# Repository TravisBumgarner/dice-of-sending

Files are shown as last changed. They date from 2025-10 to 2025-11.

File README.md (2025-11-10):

# Dice of Sending

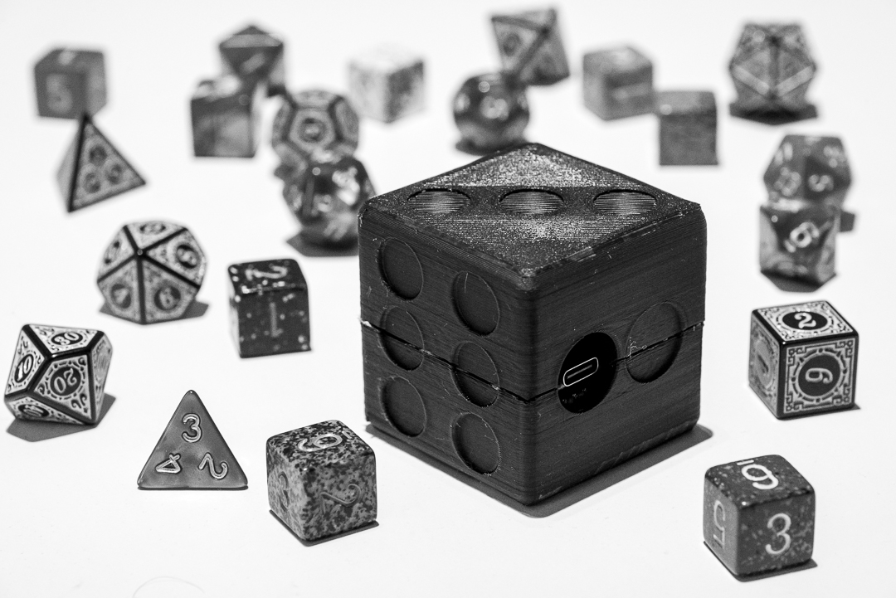
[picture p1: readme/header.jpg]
Finished D6 dice


**Wondrous Item, uncommon**

When a Dungeon Master insists you roll in plain sight, the Dice of Sending offer a clever loophole. These enchanted dice are linked by invisible arcane currents (or Bluetooth, depending on your realm’s tech level), allowing a roll in both the physical and digital planes simultaneously.

Those attuned to the Dice of Sending may appear obedient while still indulging their chaotic good nature—rolling fairly, yet unpredictably.

# Preface

This project is still a work in progress and is mostly there but there are still some rough edges.

[Join the discussion on Discord](https://discord.gg/wJ8eyUJk) (Check the `#dice-of-sending` channel).

# Fairness

With the latest version, I test rolled 210 times

- 1 - 34
- 2 - 31
- 3 - 41
- 4 - 37
- 5 - 36
- 6 - 31

# Quick Start

Full setup below.

1. Solder Seed Studio, battery, and accelerometer together.
1. Calibrate dice with `arduino/calibration/calibration.ino`
1. Add calibration values to `arduino/dice_of_sending/dice_of_sending.ino`.
1. Run website with `cd website && npm bootstrap && npm run dev` (Or visit [Dice of Sending](https://dice.pointlessprojects.com/) if still hosted.)
1. Open website, invite friends to a room, connect to dice, start playing board games.

```
const device = await navigator.bluetooth.requestDevice({
    filters: [{ namePrefix: "old-name-here" }],
    optionalServices: ["deadbeef-1234-5678-1234-56789abcdef0"],
});
```

# Future Functionality

These are things I'll maybe do in the future, or you can too!

**Low power mode**

When the dice aren't being rolled, go to sleep to save power.

# Setup

## Tools

1. Hot glue gun
1. Soldering iron
1. [Arduino IDE](https://www.arduino.cc/en/software/)

## Parts

1. 1× `USB-C cable`
1. 1× `Seeed Studio XIAO nRF52840` (Or any Arduino device with Bluetooth)
1. 1× `BMI160 accelerometer + gyroscope`
1. 1× `3.7V 60mAh 0.22Wh battery`
1. 1x 38cm x 38cm Protoboard
1. `PCB wire`

## Code

- `dice_of_sending/` — Final Code.
- `bluetooth/` — Test bluetooth communication. Upload sketch then open the `bluetooth.html` file in the browser.
- `acceleration/` — Test accelerometer. Upload sketch and open `Tools → Serial Monitor` with the Arduino software.
- `calibration/` — Calibrate dice values. Copy output to `dice_of_sending/`.

## Circuit

**References**

- [Seeed Studio XIAO nRF52840](https://wiki.seeedstudio.com/XIAO_BLE/)
- [BMI160 3 Axis Accelerometer & Gyroscope](https://how2electronics.com/interfacing-bmi160-accelerometer-gyroscope-with-arduino/)

## Soldering

1. Solder the battery to the microcontroller pads before soldering the microcontroller to the protoboard.
1. Solder the following connections between the Seeed Studio XIAO nRF52840 and BMI160 using the references above.

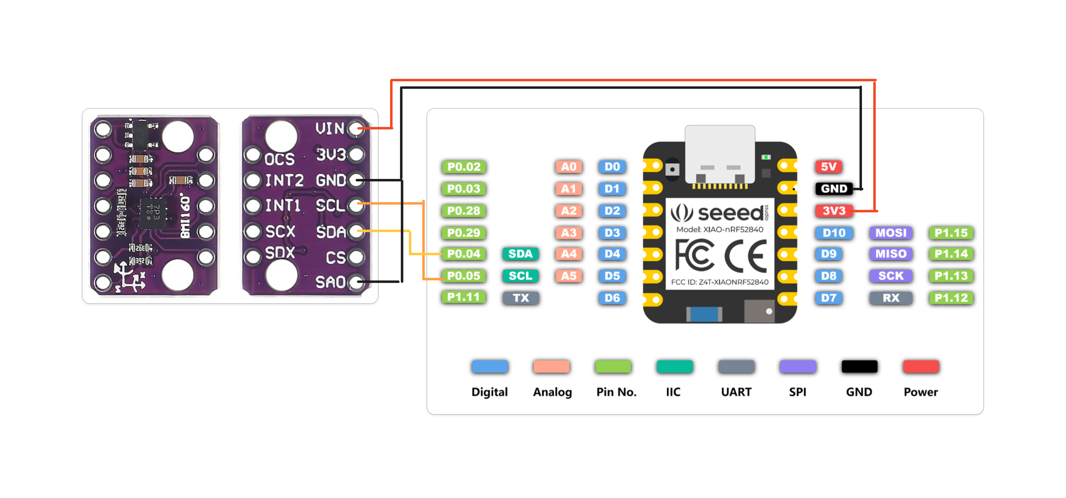
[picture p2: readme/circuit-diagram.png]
Circuit diagram

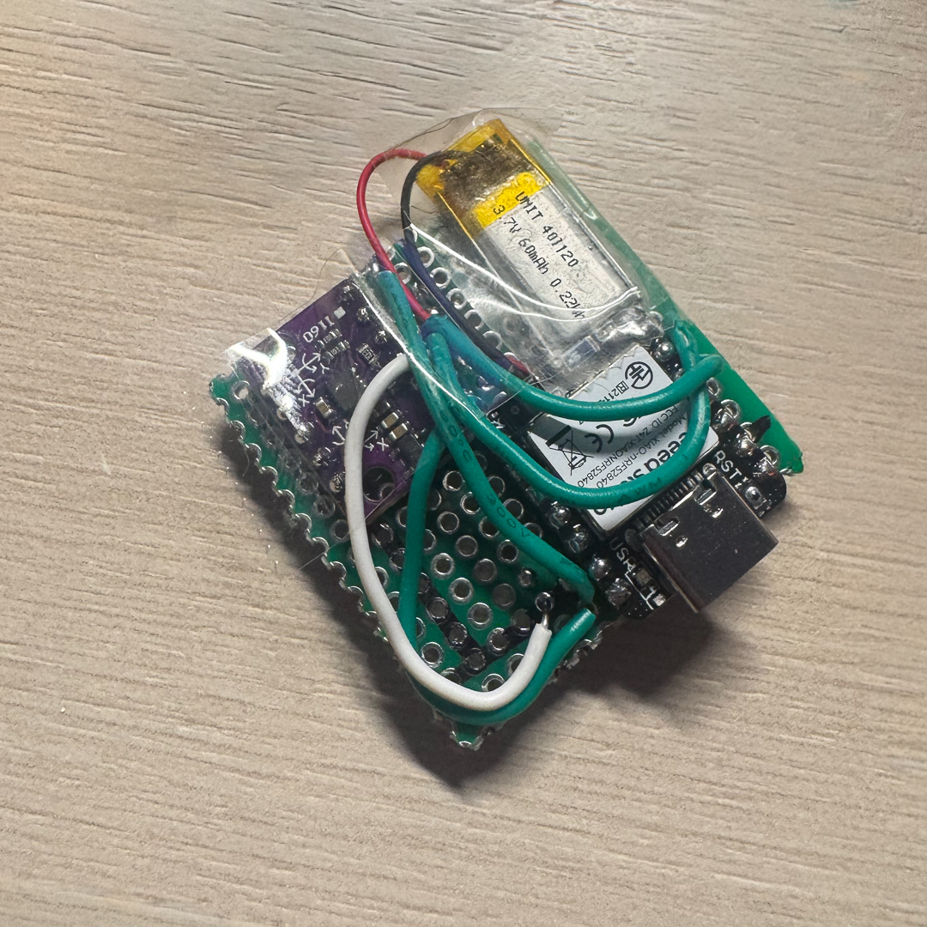
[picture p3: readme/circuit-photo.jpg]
Circuit photo


## 3D Models

- STLs can be found in `cad/`.
- Onshape models can be found [here](https://cad.onshape.com/documents?nodeId=a9d0374e84dc054d840f8403&resourceType=folder). Use the V2 Models.

1. Print models. I opted for 60% infill. 
1. Place some hot glue on each of the four corners. 
1. Place circuit inside.
1. Place some more hot glue along the edges of the circuit. 
1. Hot glue the two halves together.

## Website

The site may or may not still be hosted [here](https://dice.pointlessprojects.com/).

### Run locally

1. `cd website`
1. [Install Node and npm](https://docs.npmjs.com/downloading-and-installing-node-js-and-npm)
1. Install dependencies — `npm bootstrap`
1. Start website — `npm run dev`

### Deploy

1. Get a domain.
1. Point `website/frontend/src/services/socket.ts` towards your domain.
1. Build `npm run build` - This will give you an Express server that runs the socket connection and serves the React app.
1. Deploy somewhere.
1. Enjoy!

# Known Issues

These are either bugs in the code or quirks/shortcomings.

**Arduino Software can't find device**

Sometimes the device needs to be reconnected a few times before it shows up in Arduino.

**Bluetooth Naming**

It appears that it takes some time for the browser to recognize a name change of `BLE.setLocalName("Arduino");` within the Arduino code. If the device stops showing up and you changed the name, try searching for the old name within the HTML code:

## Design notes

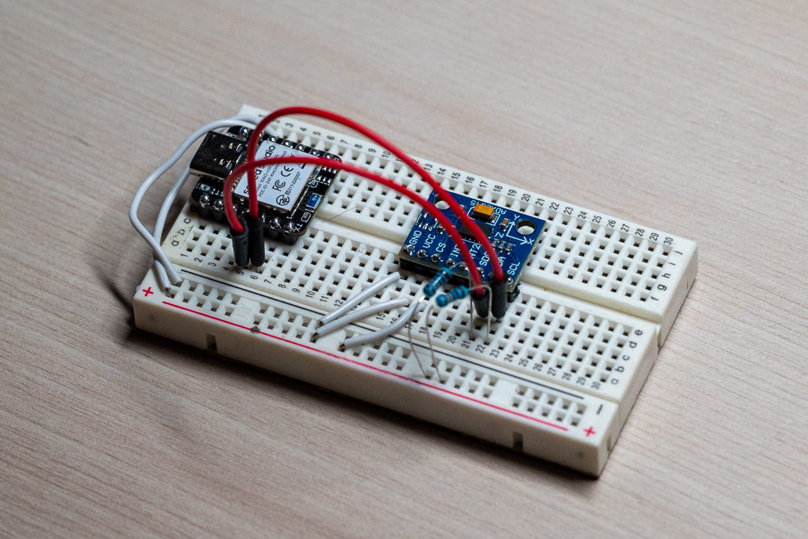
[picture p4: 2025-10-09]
readme/breadboard.jpg

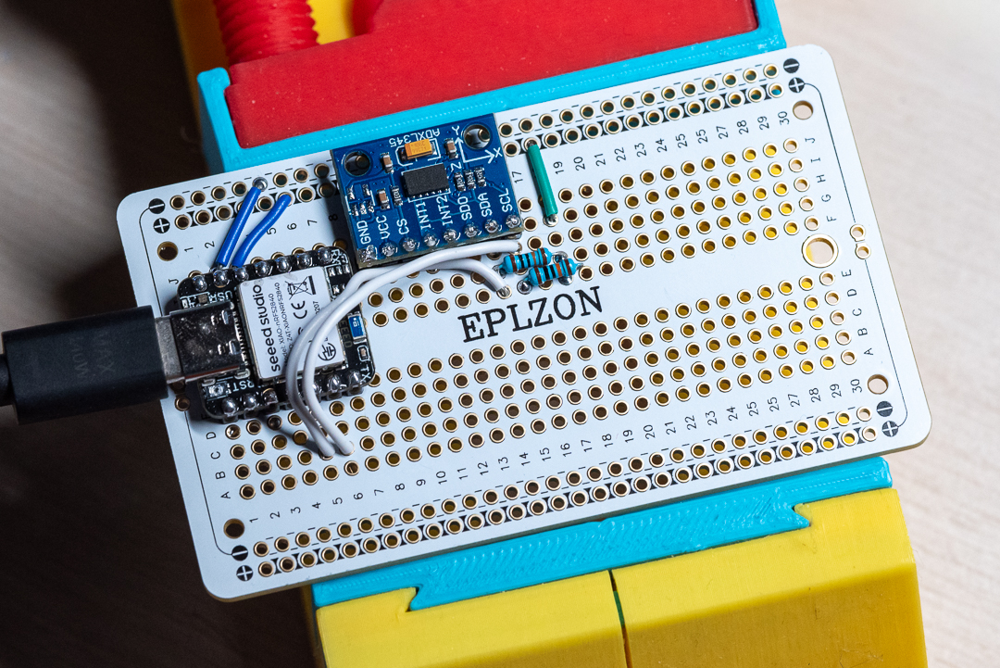
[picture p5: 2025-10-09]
readme/protoboard.jpg

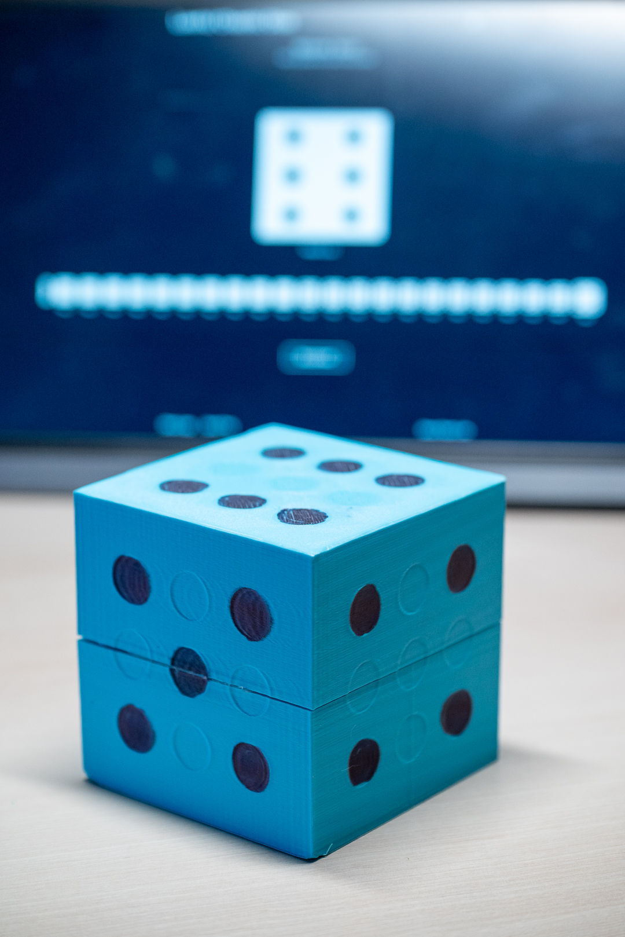
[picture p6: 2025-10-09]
readme/final.jpg

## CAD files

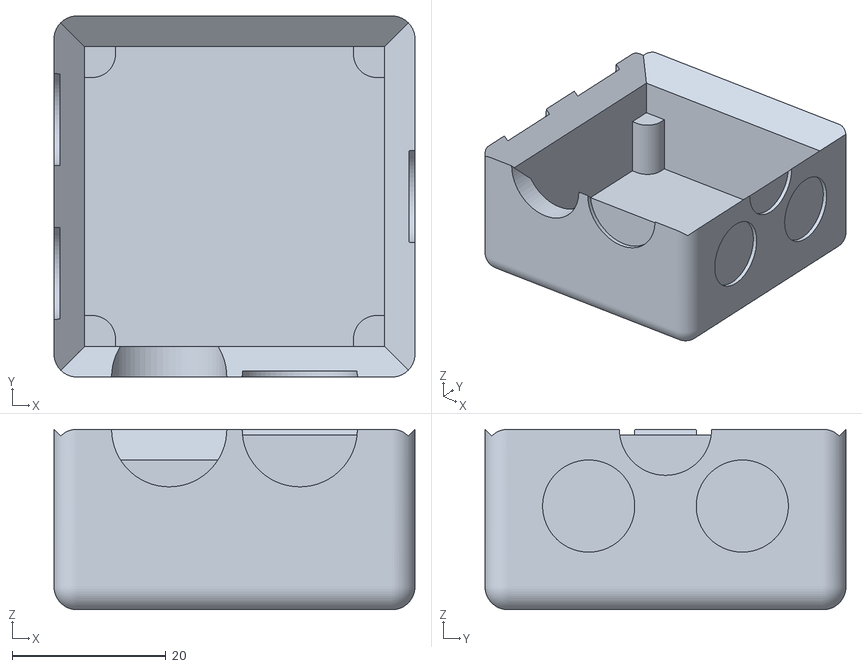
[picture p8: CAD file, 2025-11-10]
cad/Dice V3 - Bottom.stl
47.0 x 47.0 x 23.5

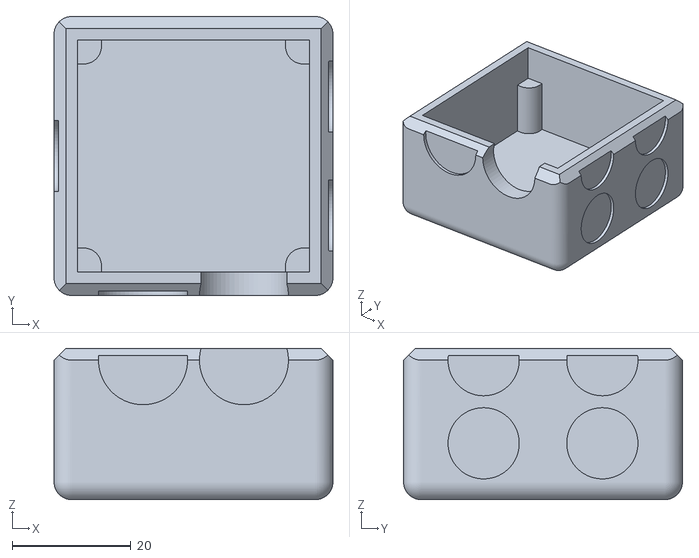
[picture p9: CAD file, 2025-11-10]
cad/Dice V3 - Top.stl
47.0 x 47.0 x 25.5

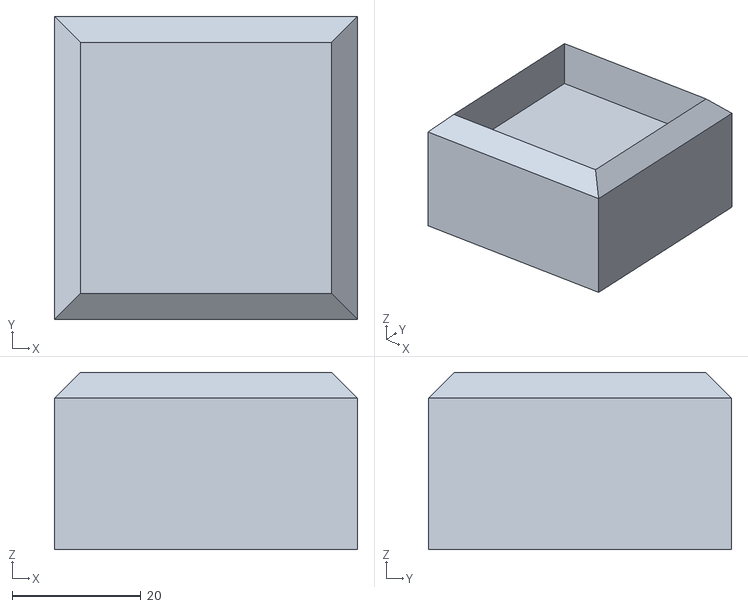
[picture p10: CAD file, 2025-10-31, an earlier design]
archive/cad/Dice V2 - Top.stl
47.0 x 47.0 x 27.5

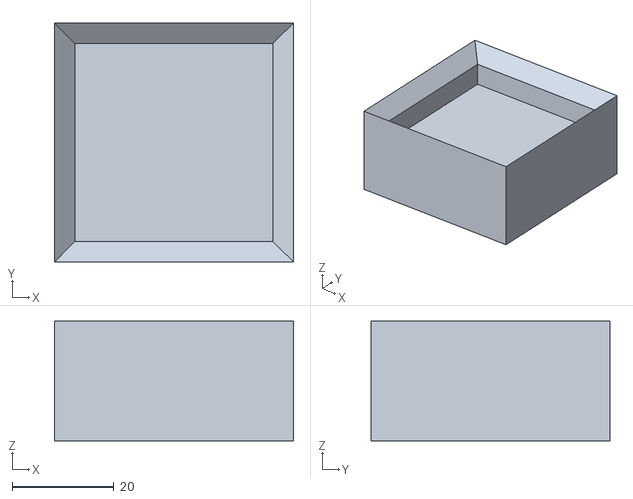
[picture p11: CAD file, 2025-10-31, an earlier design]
archive/cad/Dice V2 - Bottom.stl
47.0 x 47.0 x 23.5

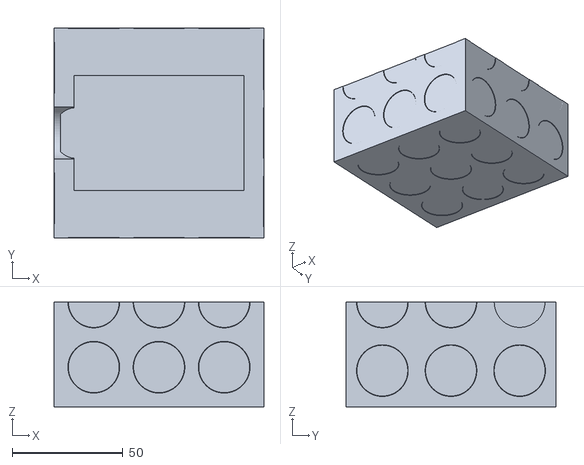
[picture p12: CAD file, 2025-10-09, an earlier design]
archive/cad/Dice V1 - Top.stl
95.0 x 95.0 x 47.5

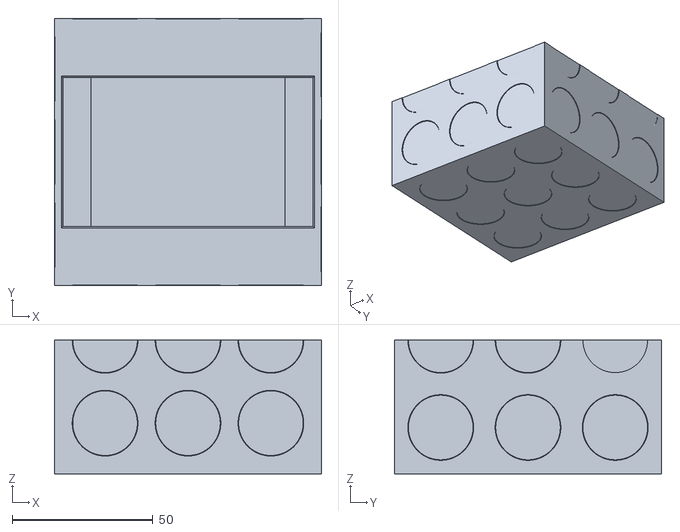
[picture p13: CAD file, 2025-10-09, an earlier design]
archive/cad/Dice V1 - Bottom.stl
95.0 x 95.0 x 47.5

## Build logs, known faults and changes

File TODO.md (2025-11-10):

- [ ] Bug - Sometimes, a dice roll shows twice in the browser.
- [ ] New - Implement low power mode.
- [ ] Bug - Sliding dice without rolling triggers a dice roll.
- [ ] Posts
  - [ ] Thingiverse
  - [ ] hackaday.io
  - [ ] Reddit - dnd arduino, where else?

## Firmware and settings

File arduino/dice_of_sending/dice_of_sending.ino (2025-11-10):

#include <Wire.h>
#include <ArduinoBLE.h>
#include <BMI160Gen.h>

// ---------------------- Calibration ----------------------

float MATCH_THRESHOLD = 0.2;

float faceCalibrations[6][3] = {
  {-0.017, 0.045, -0.943},
  {-0.007, -1.031, -0.007},
  {0.027, -0.099, 1.048},
  {0.031, 0.970, 0.112},
  {1.008, -0.029, 0.051},
  {-0.994, -0.014, 0.056}
};

// ---------------------- BLE ----------------------

BLEService diceService("deadbeef-1234-5678-1234-56789abcdef0");
BLEStringCharacteristic faceCharacteristic(
  "deadbeef-1234-5678-1234-56789abcdef1",
  BLERead | BLENotify | BLEWrite,
  50);

// ---------------------- State ----------------------

int currentFace = -1;
int lastDetectedFace = -1;
int stableCount = 0;
const int STABLE_THRESHOLD = 5;

// ---------------------- Blink Helpers ----------------------

void blinkError(int count) {
  for (;;) {
    for (int i = 0; i < count; i++) {
      digitalWrite(LED_BUILTIN, LOW);
      delay(150);
      digitalWrite(LED_BUILTIN, HIGH);
      delay(150);
    }
    delay(600);
  }
}

void blinkSlow() {
  digitalWrite(LED_BUILTIN, LOW);
  delay(300);
  digitalWrite(LED_BUILTIN, HIGH);
  delay(1200);
}

// ---------------------- BLE/Debug Helpers ----------------------

void sendDebug(const char* msg) {
  char buf[60];
  snprintf(buf, sizeof(buf), "Debug: %s", msg);
  faceCharacteristic.writeValue(buf);
}

void sendRoll(int face) {
  char buf[32];
  snprintf(buf, sizeof(buf), "Roll: %d", face);
  faceCharacteristic.writeValue(buf);
}

// ---------------------- Setup ----------------------

void setup() {
  delay(300);
  pinMode(LED_BUILTIN, OUTPUT);
  digitalWrite(LED_BUILTIN, HIGH);  // off

  if (!BMI160.begin(BMI160GenClass::I2C_MODE, 0x68)) {
    sendDebug("BMI160 init failed!");
    blinkError(2);
  }
  sendDebug("BMI160 ready");

  if (!BLE.begin()) {
    sendDebug("BLE init failed!");
    blinkError(3);
  }

  BLE.setLocalName("Dice of Sending");
  BLE.setDeviceName("Dice of Sending");
  BLE.setAdvertisedService(diceService);
  diceService.addCharacteristic(faceCharacteristic);
  BLE.addService(diceService);

  // -------- Ping/Pong handler (fixed) --------
  // -------- Ping/Pong handler --------
  faceCharacteristic.setEventHandler(BLEWritten, [](BLEDevice central, BLECharacteristic characteristic) {
    int len = characteristic.valueLength();
    const uint8_t* data = characteristic.value();

    String msg;
    for (int i = 0; i < len; i++) msg += (char)data[i];

    if (msg == "Ping") {
      characteristic.writeValue("Pong");
    }
  });

  BLE.advertise();
  sendDebug("BLE Dice advertising");
}  // ✅ this was missing — closes setup()


// ---------------------- Loop ----------------------

void loop() {
  BLEDevice central = BLE.central();

  if (central) {
    sendDebug("BLE connected");
    digitalWrite(LED_BUILTIN, LOW);  // solid ON

    while (central.connected()) {
      int ax, ay, az;
      BMI160.readAccelerometer(ax, ay, az);
      float fx = ax / 16384.0;
      float fy = ay / 16384.0;
      float fz = az / 16384.0;

      int detectedFace = detectFace(fx, fy, fz);

      if (detectedFace == -1) {
        currentFace = -1;
        stableCount = 0;
      } else if (detectedFace == lastDetectedFace) {
        stableCount++;
        if (stableCount >= STABLE_THRESHOLD && detectedFace != currentFace) {
          currentFace = detectedFace;
          sendRoll(currentFace + 1);
        }
      } else {
        stableCount = 0;
        lastDetectedFace = detectedFace;
      }

      delay(100);
    }
  } else {
    blinkSlow();
  }
}

// ---------------------- Face Detection ----------------------

int detectFace(float x, float y, float z) {
  float minDist = 9999;
  int best = -1;
  for (int i = 0; i < 6; i++) {
    float dx = x - faceCalibrations[i][0];
    float dy = y - faceCalibrations[i][1];
    float dz = z - faceCalibrations[i][2];
    float dist = sqrt(dx * dx + dy * dy + dz * dz);
    if (dist < minDist) {
      minDist = dist;
      best = i;
    }
  }
  return (minDist < MATCH_THRESHOLD) ? best : -1;
}

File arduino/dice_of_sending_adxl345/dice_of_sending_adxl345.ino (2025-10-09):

#include <Wire.h>
#include <Adafruit_ADXL345_U.h>
#include <ArduinoBLE.h>

// ---------------------- Calibration ----------------------

// Use calibration sketch to calculate these values. 

// How "close" a reading must be to a stored face vector to count as valid
// (lower = stricter). Usually 1.5–2.5 works well for ±1g noise.
float MATCH_THRESHOLD = 2.0;

// Each row: {x, y, z} average when that face is UP
// Use calibration.ino sketch to tweak these values.
float faceCalibrations[6][3] = {
  {-0.16, -0.27, 11.77},  // Face 1
  {-0.27, 9.41, 1.06},  // Face 2
  {-9.85, -0.16, 1.02},  // Face 3
  {0.08, -10.00, 1.73},  // Face 4
  {9.85, 1.26, 1.92},  // Face 5
  {-0.35, -0.35, -8.04}   // Face 6
};

// ---------------------- Accelerometer ----------------------
Adafruit_ADXL345_Unified accel = Adafruit_ADXL345_Unified(12345);
bool rolling = false;

// ---------------------- BLE ----------------------
BLEService simpleService("deadbeef-1234-5678-1234-56789abcdef0");
BLEStringCharacteristic simpleChar("deadbeef-1234-5678-1234-56789abcdef1",
                                   BLERead | BLEWrite | BLENotify, 20);

// ---------------------- Stability Tracking ----------------------
unsigned long stableStart = 0;
const unsigned long STABLE_TIME_MS = 1000;  // must rest this long before confirming result
int lastFace = 0;

// ---------------------- Setup ----------------------
void setup() {
  Serial.begin(115200);
  while (!Serial);

  Serial.println("Starting BLE + ADXL345 Dice...");

  // --- Accelerometer setup ---
  if (!accel.begin()) {
    Serial.println("No ADXL345 detected ... check wiring!");
    while (1);
  }
  accel.setRange(ADXL345_RANGE_16_G);
  Serial.println("ADXL345 detected at 0x53");

  // --- BLE setup ---
  if (!BLE.begin()) {
    Serial.println("Starting BLE failed!");
    while (1);
  }

  BLE.setLocalName("ArduinoDice");
  BLE.setAdvertisedService(simpleService);

  simpleService.addCharacteristic(simpleChar);
  BLE.addService(simpleService);

  simpleChar.writeValue("Ready to roll!");
  BLE.advertise();

  Serial.println("BLE peripheral is now advertising as 'ArduinoDice'");
}

// ---------------------- Main Loop ----------------------
void loop() {
  BLEDevice central = BLE.central();

  if (central) {
    Serial.print("Connected to central: ");
    Serial.println(central.address());

    while (central.connected()) {
      // --- Handle BLE writes ---
      if (simpleChar.written()) {
        Serial.print("Got from Mac: ");
        Serial.println(simpleChar.value());
      }

      // --- Handle dice motion ---
      sensors_event_t event;
      accel.getEvent(&event);

      float x = event.acceleration.x;
      float y = event.acceleration.y;
      float z = event.acceleration.z;

      float mag = sqrt(x * x + y * y + z * z);
      static float prevMag = 0;
      float delta = fabs(mag - prevMag);
      prevMag = mag;

      bool isMoving = delta > 0.25;  // sensitivity threshold

      if (isMoving) {
        if (!rolling) {
          Serial.println("Rolling...");
          rolling = true;
          lastFace = 0;
        }
      } else {
        int face = mapToDieFace(x, y, z);

        if (rolling) {
          // just stopped moving
          rolling = false;
          stableStart = millis();
          lastFace = face;
        } else {
          // still stable — check if it stayed on same side long enough
          if (face != 0 && face == lastFace && (millis() - stableStart) > STABLE_TIME_MS) {
            Serial.print("Result: ");
            Serial.println(face);

            char msg[10];
            sprintf(msg, "Face %d", face);
            simpleChar.writeValue(msg);

            lastFace = 0;  // prevent repeat sends
          }
        }
      }

      delay(100);
    }

    Serial.print("Disconnected from: ");
    Serial.println(central.address());
  }
}

// ---------------------- Dice Face Mapping ----------------------
int mapToDieFace(float x, float y, float z) {
 int bestFace = 0;
  float bestDist = 9999;

  for (int i = 0; i < 6; i++) {
    float dx = x - faceCalibrations[i][0];
    float dy = y - faceCalibrations[i][1];
    float dz = z - faceCalibrations[i][2];
    float dist = sqrt(dx * dx + dy * dy + dz * dz);

    if (dist < bestDist) {
      bestDist = dist;
      bestFace = i + 1;
    }
  }

  // Only count as valid if we're clearly close to a known face
  if (bestDist < MATCH_THRESHOLD) {
    return bestFace;
  } else {
    // Too tilted or in between sides
    return 0;
  }
}

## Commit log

2025-10-05 added stl
    [dice_half.stl]
2025-10-06 prod deploy; calibration code; style updates
2025-10-09 Images, readme updates, website updates; STLs
    [Dice V1 - Bottom.stl, Dice V1 - Top.stl, dice_half.stl]
2025-11-06 Code Cleanup; Documentation; Bug Fixes (#1)
    * done
    * fix dice sides
    * fix circuit image
    * fixed ping pong
    [Dice V1 - Bottom.stl, Dice V1 - Top.stl]
2025-11-10 [SSP-1045] Final cleanup (#2)
    * update CAD models and photos
    * x
    [Dice V2 - Bottom.stl, Dice V2 - Top.stl, Dice V3 - Bottom.stl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]
